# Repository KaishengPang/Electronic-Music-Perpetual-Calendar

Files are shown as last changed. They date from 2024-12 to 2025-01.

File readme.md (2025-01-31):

# Electronic Music Perpetual Calendar 🕰️📅
## 外观展示⏰

<div align=center>
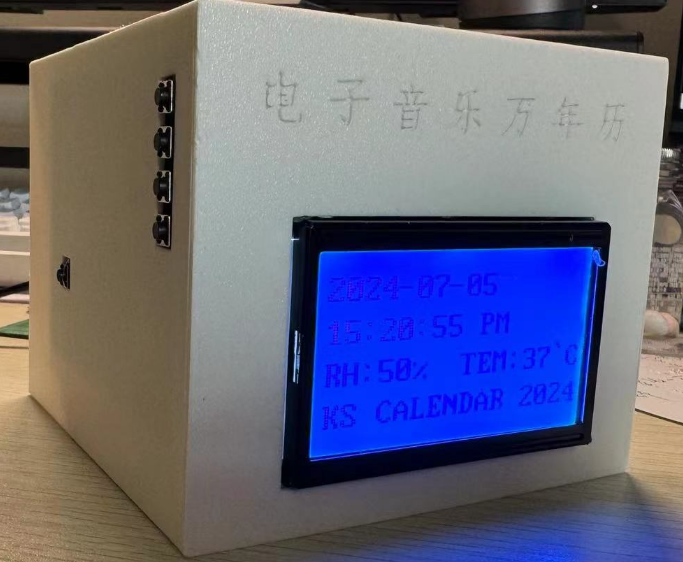
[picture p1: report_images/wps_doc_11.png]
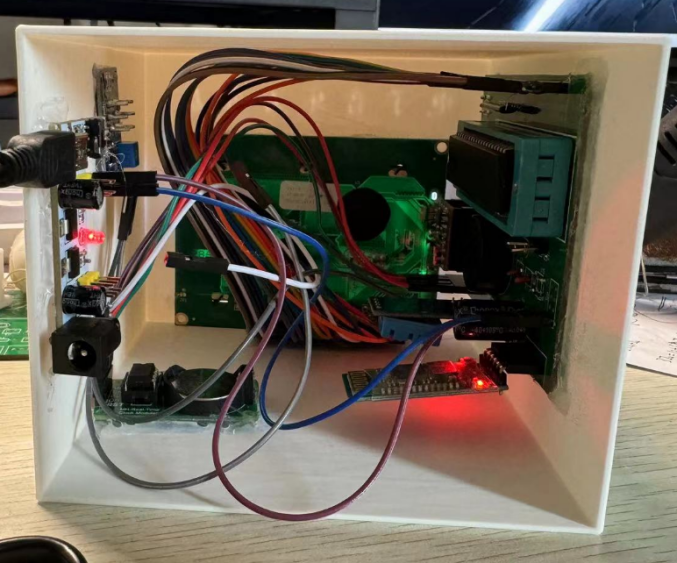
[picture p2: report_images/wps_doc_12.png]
 
</div>

欢迎来到 Electronic Music Perpetual Calendar 项目！本项目基于 [Smart-Calendar-Clock](https://github.com/genglinWang/Smart-Calendar-Clock) 进行了全面优化与功能扩展，打造了一款融合物联网与智能交互的创新硬件产品。

> 📜 本项目为山东大学信息学院《开放性创新实践Ⅰ—硬件》课程成果

## 项目亮点 ✨✨✨

### 全栈式开发闭环
🖨️ **3D打印一体化外壳** - SolidWorks建模实现物理按键与PCB板完美嵌合  
🔩 **双版本PCB迭代** - 从15x10cm优化至8.6x7.4cm，支持背焊式按键设计  
🔥 **火灾应急系统** - MQ-2烟雾传感器+短信报警双保险机制  

### 功能全景图
📅 **日历系统**  
- 公历/农历双模式 | 二十四节气 | 星期显示 
- 事件提醒（生日/会议/作业）⏰ 提前1天弹窗预警  
- 闹钟时间设置，闹钟时间到进行声光报警提示🚨

🌡️ **环境感知**  
- DHT11温湿度实时监测  
- 蓝牙天气同步（晴/雨/多云等8种状态）
- MQ-2烟雾传感器🔥+短信✉️报警双保险机制  

🎵 **智能交互**  
- 手机APP进行时间调整、事项提醒、天气更新
- JQ8900音乐芯片支持6首闹铃可选  
- MIT App Inventor开发跨平台控制APP  

<div align=center>
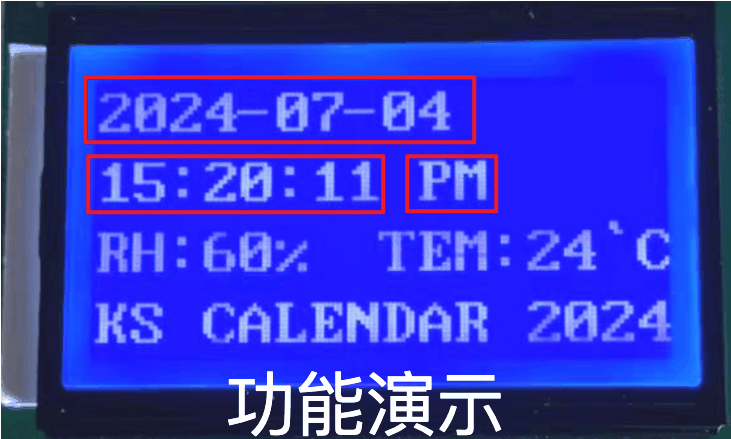
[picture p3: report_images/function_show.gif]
 
</div>

## 硬件架构 📐
### 原理图

<div align=center>
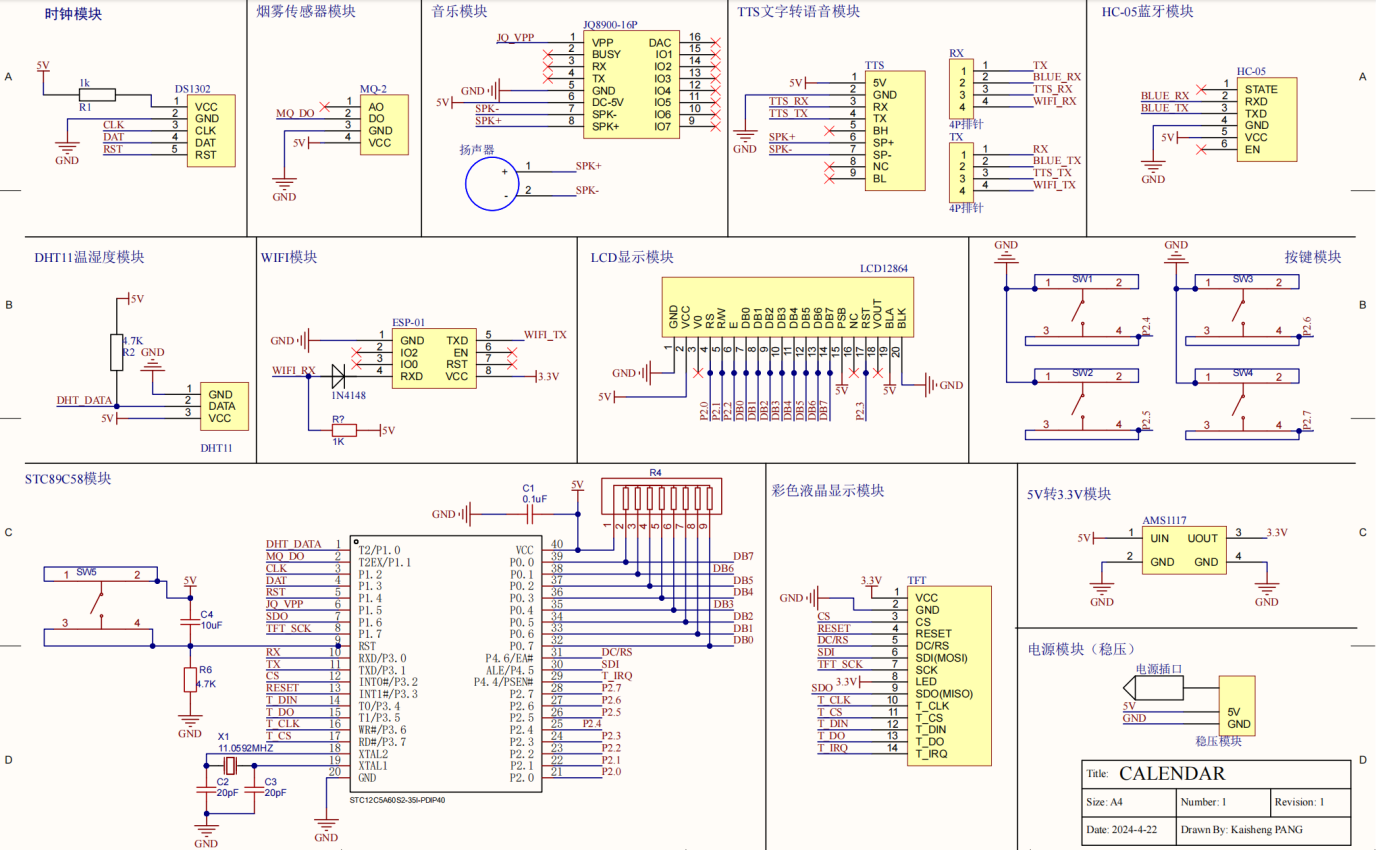
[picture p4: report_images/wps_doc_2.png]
 
</div>

### 3D打印效果图

<div align=center>
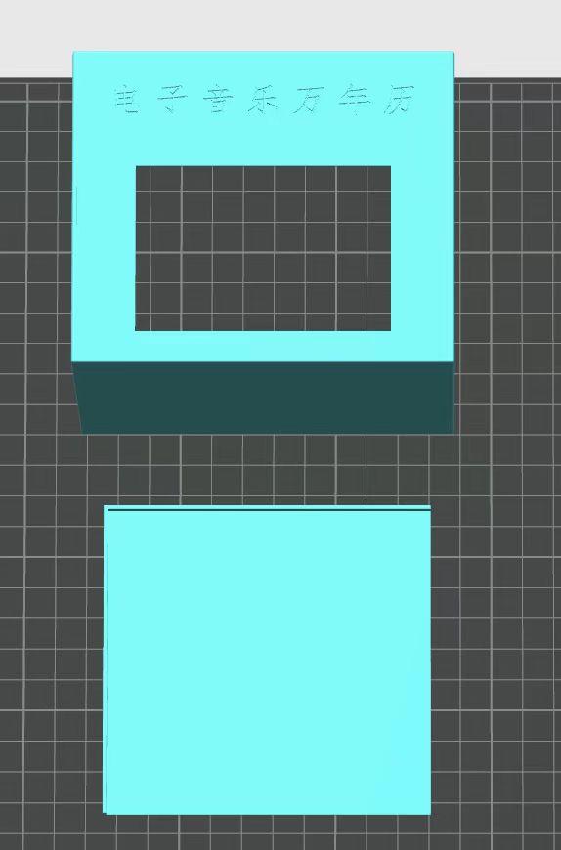
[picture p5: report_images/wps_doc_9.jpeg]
 
</div>

### PCB设计效果图

<div align=center>
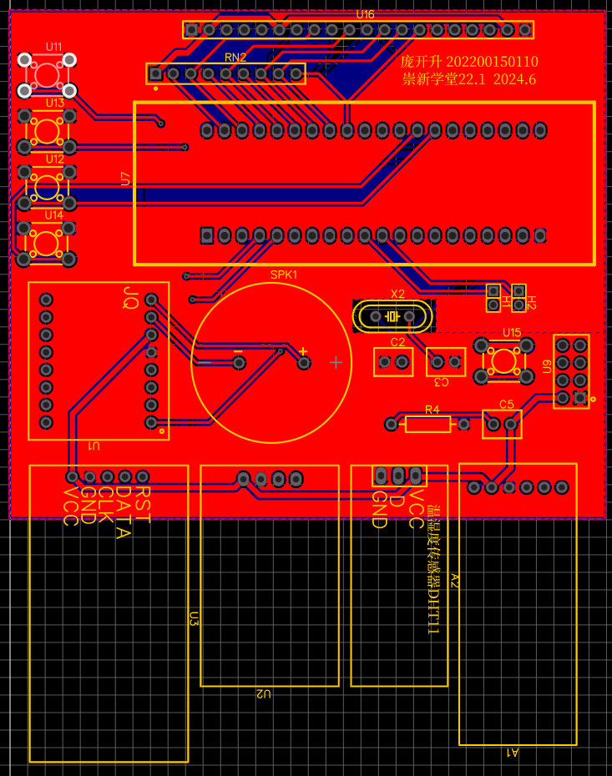
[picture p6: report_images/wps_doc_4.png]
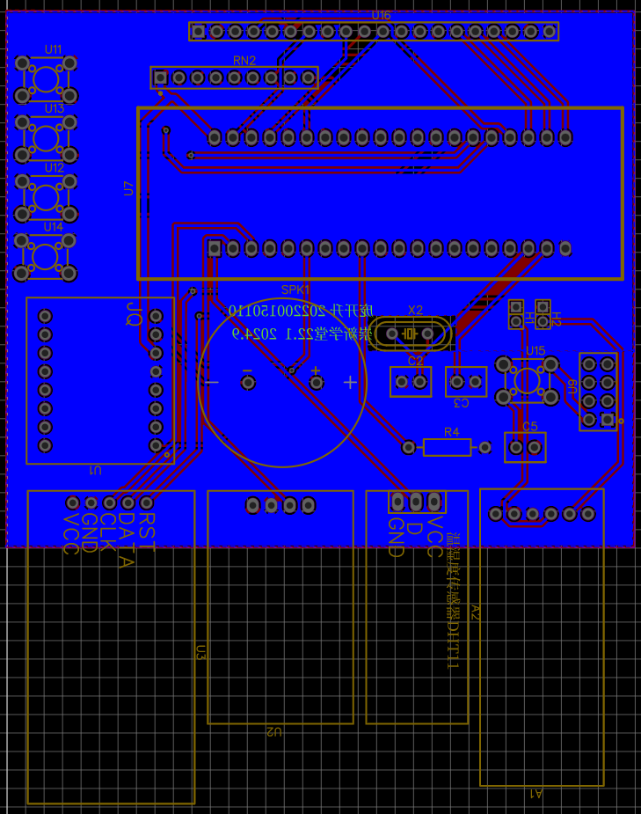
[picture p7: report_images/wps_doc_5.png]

</div>

### 核心模块清单
| 模块 | 型号 | 特性 |
|---|---|---|
| MCU | STC12C5A6052 | 低功耗高速8051内核 |
| 时钟 | DS1302 | 纽扣电池供电持续计时 |
| 显示 | LCD12864 | 自定义汉字库支持 |
| 音乐 | JQ8900-16P | 播放自定义铃声 |
| 通信 | HC-05蓝牙 | 安卓/iOS全平台兼容 |
| 传感器 | MQ-2+DHT11 | 火灾/温湿度双重监测 |

### PCB进化史
<div align=center>
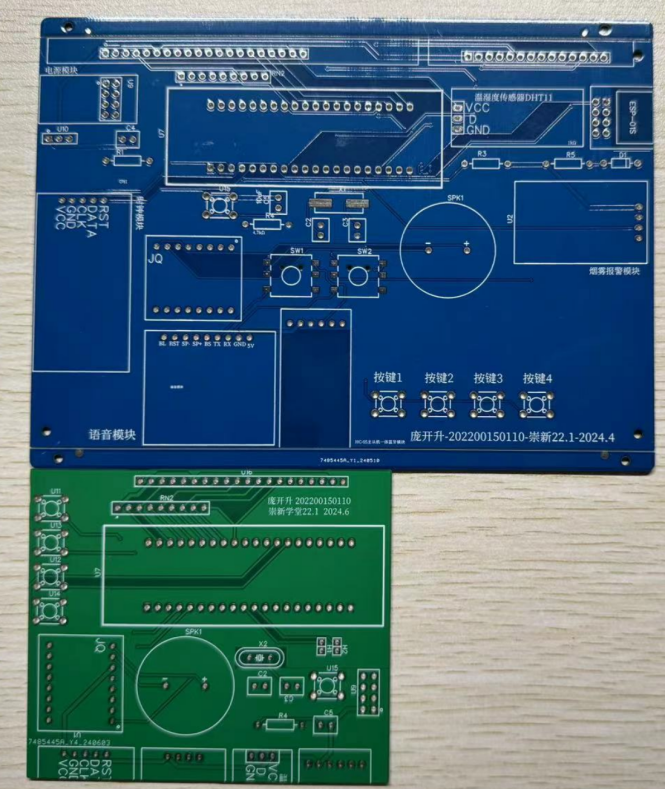
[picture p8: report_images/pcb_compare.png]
 
</div>

- **V1痛点**：WIFI/蓝牙冲突 | 布局冗余 | 供电不稳  
- **V2突破**：精简模块位置 | 背焊式按键设计 | 与3D打印结合

## 项目开发流程 🛠️

### 1. 原理图设计 📐
利用 **Altium Designer** 设计该系统的原理图：
- **模块化设计**：将系统分为MCU、时钟、传感器、显示、通信等模块。
- **电平转换**：在WIFI_RX处添加电平转换设计，确保信号稳定性。
- **模块选择**：
  - MCU：STC12C5A6052
  - 时钟：DS1302
  - 传感器：MQ-2（烟雾）、DHT11（温湿度）
  - 显示：LCD12864
  - 通信：HC-05（蓝牙）、ESP-01（WiFi）
  - 电源：AMS1117（5V转3.3V）

### 2. PCB设计 🖨️
利用 **Altium Designer** 设计PCB板图，并委托制板厂家加工：
- **PCB尺寸**：第一版为15x10cm，第二版优化为8.6x7.4cm。
- **线宽设置**：供电和接地线宽为30mil，其余线宽为10mil。
- **文字标识**：在PCB板上添加学号和姓名文字标识。
- **优化改进**：
  - 去掉ESP-01S WiFi模块，避免与蓝牙冲突。
  - 使用排针形式引出TX、RX，解决开关自动复位问题。
  - 加入稳压模块，解决DC供电电压偏差问题。

### 3. 焊接与调试 🔧
焊接元器件并进行实物调试：
- **第一版焊接**：LCD12864显示不稳定，PCB接触不良，通讯复杂。
- **第二版焊接**：焊接效果良好，蓝牙通讯恢复正常，空间利用率高。
- **调试重点**：
  - 确保LCD12864显示稳定。
  - 测试蓝牙、WiFi通信功能。
  - 验证温湿度传感器和烟雾传感器数据准确性。

### 4. 3D打印与外壳制作 🖌️
进行 **3D打印**，制作配套机壳：
- **设计工具**：使用 **SolidWorks** 进行建模。
- **外壳设计**：
  - 创建基本外壳，添加显示屏、按钮、烟雾传感器的开口。
  - 调整外壳厚度，添加圆角，增强美观性和结构强度。
- **按钮设计**：从背面焊接按钮，搭配3D打印外壳，实现原始触发且灵敏。
- **固定方式**：使用热熔胶固定内部元件，确保稳固性。

### 5. 设计报告编写 📄
编写设计报告，包含软硬件设计思路和效果展示：
- **硬件设计**：
  - 原理图设计思路。
  - PCB布局优化过程。
  - 焊接调试问题与解决方案。
- **软件设计**：
  - 蓝牙连接逻辑。
  - 时间、闹钟设置功能实现。
  - 事件提醒与天气显示逻辑。
- **效果展示**：
  - 3D外壳效果图。
  - 功能演示截图（时间显示、温湿度检测、闹钟设置等）。
  - 手机APP界面截图。

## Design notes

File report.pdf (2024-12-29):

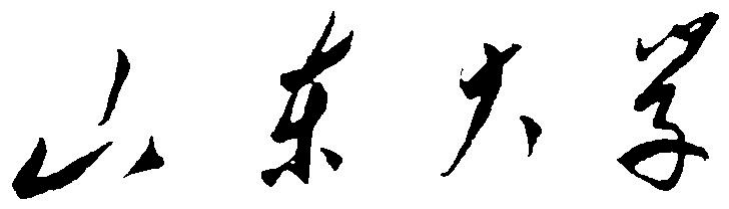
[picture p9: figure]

# 崇新学堂

### 2023－2024 学年第二学期

# 电子音乐万年历报告

课 | 程 | 名 | 称： 开放性创新实践Ⅰ—硬件
课 | 程 | 部 | 分： | 硬件报告
专 | 业 | 班 | 级： | 崇新 22.1
学 | 生 | 姓 | 名： | 庞开升
学 | 生 | 学 | 号：
报 | 告 | 时 | 间： | 2024.7.3

山东大学·崇新学堂·实验报告

目录

### 1 项目功能要求

### 1.1 基本功能

●年、月、日、时、分、秒、星期的显示与设置
●AM、PM 设置与显示
●农历年月日、二十四节气显示
●闹钟时间设置，闹钟时间到进行声光报警提示
●温湿度检测与显示

### 1.2 高级功能

●闹钟音乐选择（采用 TF 卡或录音芯片存储音乐数据）
●手机通过蓝牙或 WiFi 网络连接该万年历，通过手机 APP 可以完成基本功能中的所有 设置功能
●事件提示设置，可以通过手机或电脑将重要事件信息发送给系统，系统在事件发生前 一日通过字幕提醒（比如某某人的生日，某某会议等）
●通过编写 Android 手机程序或者将万年历连接到电脑上，获得网上天气预报数据，并 将该数据通过蓝牙或 WiFi 网络传递给音乐万年历，万年历可以完成天气信息显示 ●火灾检测与声光报警，报警形势可以是短信。

### 2 实现步骤

●利用 Altium Designer 设计该系统的原理图
●利用 Altium Designer 设计该系统的 PCB 板图，并委托制板厂家加工，板上要有学号 姓名文字标识
●焊接元器件进行实物调试
●进行 3D 打印，配套机壳，做成能实用的万年历！
●编写设计报告，包含相应的软硬件设计思路描述，设计效果展示

### 3 原理图绘制

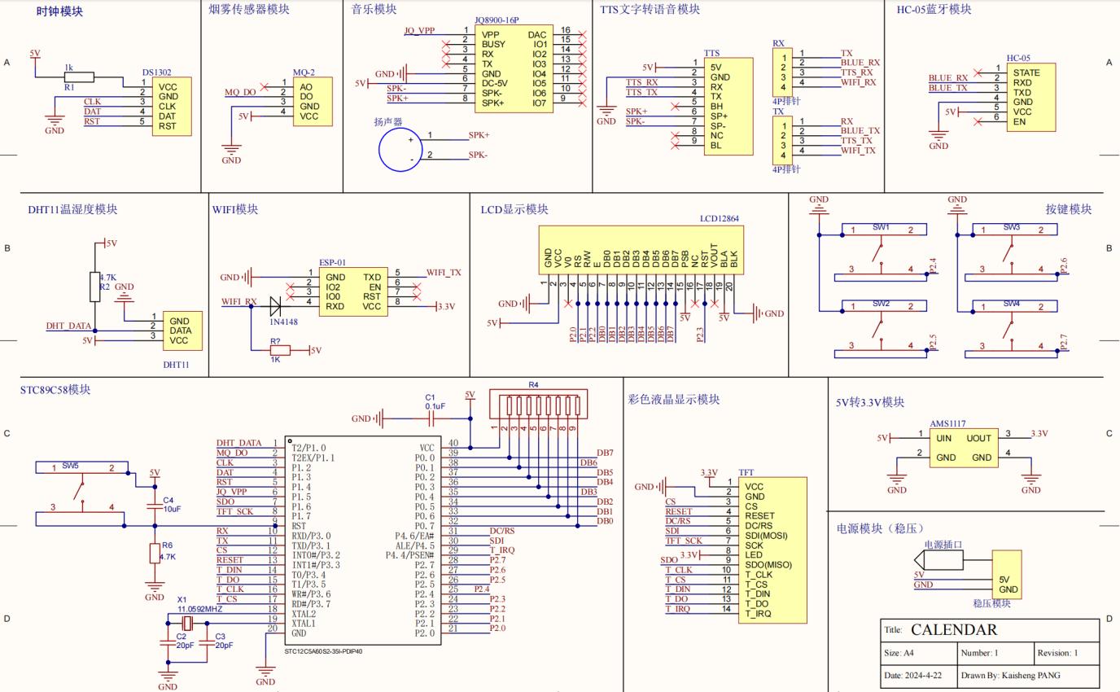
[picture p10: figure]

根据设计要求，设计了第一版原理图，根据老师提示，在 WIFI_RX 处添加电平转 换设计。

### 3.1 设计 PCB 板

### 3.1.1 第一版 PCB

根据原理图设计 PCB，因为显示屏占据空间较大，选用 15*10 尺寸的 PCB 板，供 电和接地线宽为 30mil，其余线宽为 10mil。这是第一版的 PCB，但经过测试，发现存 在很多问题。

模块名称 | 具体选择
MCU | STC12C5A60S2
时钟 | DS1302
烟雾传感 | MQ-2
音乐 | JQ8900-16P
文字转语音 | TTS
蓝牙 | HC-05
温湿度传感 | DHT11
WIFI | ESP-01
LCD 显示 | LCD12864
彩色液晶显示 | TFT
5V 转 3.3V | AMS1117

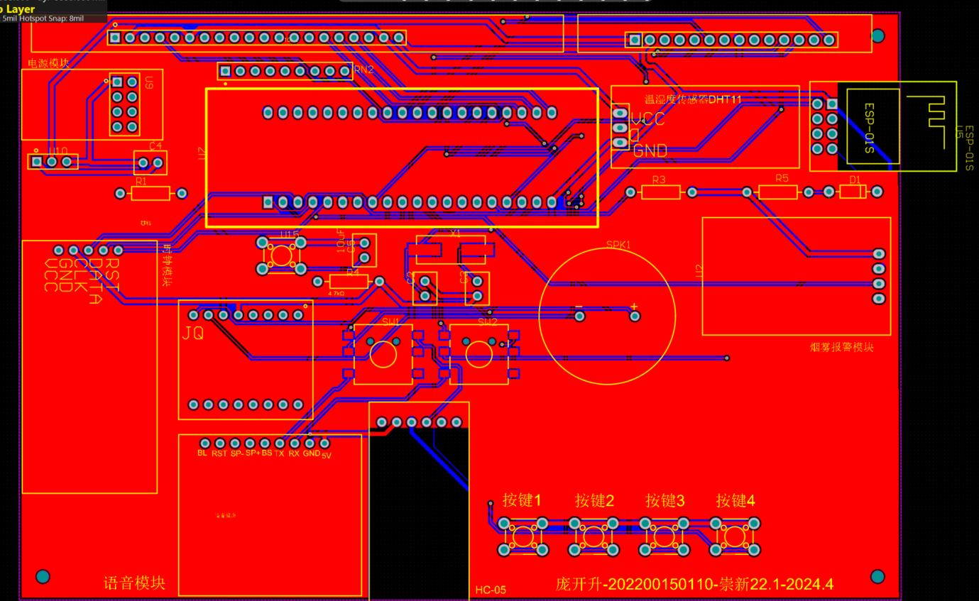
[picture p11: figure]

问题汇总及修正解决：

序号 | 问题描述 | 解决方案
1 | PCB 设计的模块方向和大小造成空间浪费 | 改进 PCB 布局与设计
2 | 同时使用ESP-01S WIFI和HC-05冲突且意义不大 去掉 ESP-01S
3 | TX、RX 分别要连接三个模块，所以使用了一款
| 五个方向的开关，可是这款开关会自动复位！ | 换成排针形式，将 TX、RX
| | 各自引出
4 | TFT 显示内容太占据内存，C58 不能胜任 | 去掉 TFT 显示屏
5 | DC 供电电压偏差太大 | 加入稳压模块

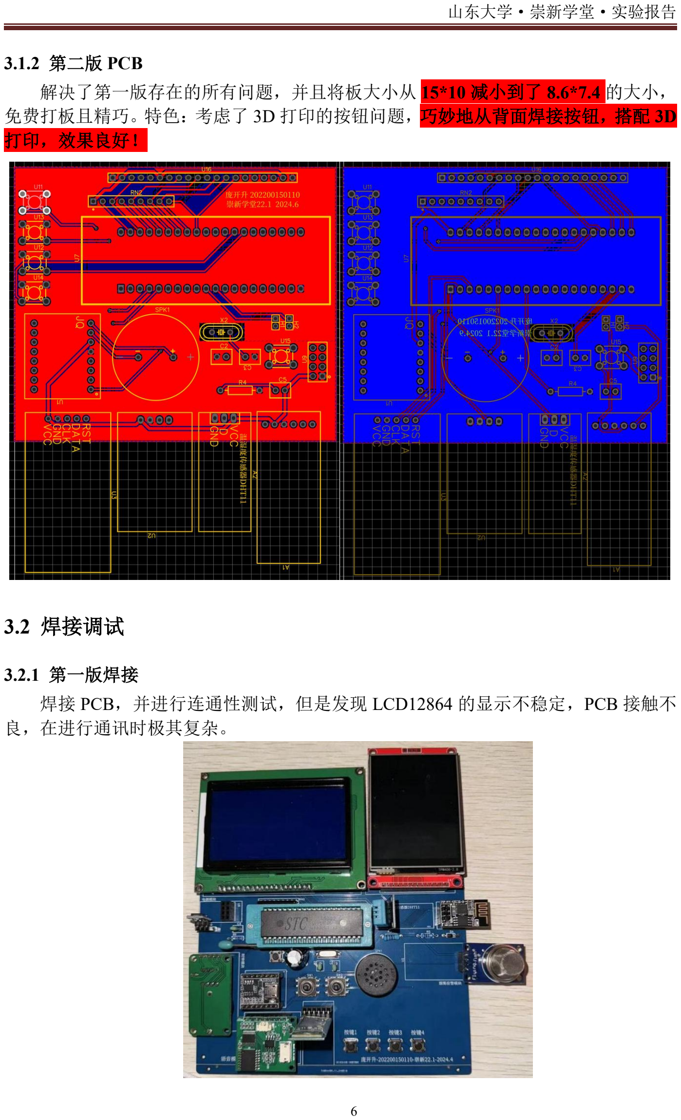
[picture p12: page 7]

### 3.1.2 第二版 PCB

解决了第一版存在的所有问题，并且将板大小从 15*10 减小到了 8.6*7.4 的大小， 免费打板且精巧。特色：考虑了 3D 打印的按钮问题，巧妙地从背面焊接按钮，搭配 3D 打印，效果良好！

### 3.2 焊接调试

### 3.2.1 第一版焊接

焊接 PCB，并进行连通性测试，但是发现 LCD12864 的显示不稳定，PCB 接触不 良，在进行通讯时极其复杂。

### 3.2.2 第二版焊接

这次焊接效果良好，大大节约了空间，充分利用板外空间，蓝牙通讯也恢复正常。

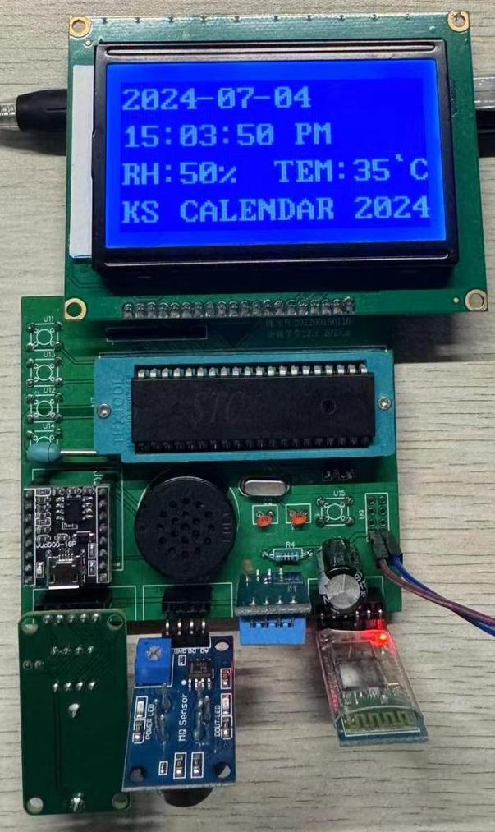
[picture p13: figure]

### 3.2.3 第一、二次 PCB 比较

很直观地看到了 PCB 制版的差别，提升显著。

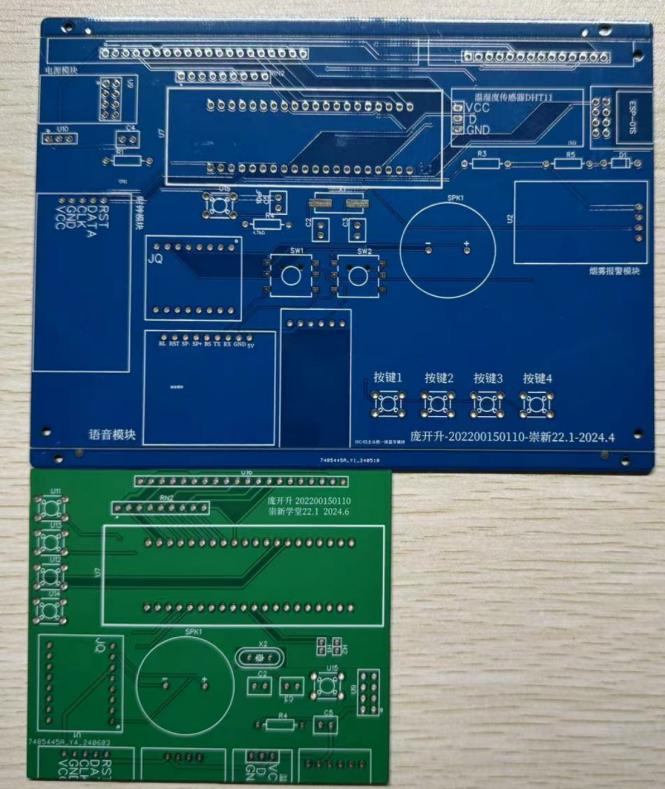
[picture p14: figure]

4 3D 外壳制作

使用 SolidWorks 建模，制作了一个外壳以及一个后盖，将显示屏、按钮、烟雾传 感器进行挖孔，将器件从里面穿出，便于显示、操控与检测。
步骤如下：
1.创建基本外壳
●在前视平面上绘制一个矩形。
●使用拉伸凸台/基体功能将矩形拉伸成一个长方体，这将成为外壳的基本形状。
2. 添加开口和孔
●在合适的平面上绘制所需的开口和孔的轮廓。
●使用切除拉伸功能来切除这些开口和孔。可以根据实际需要调整开口和孔的位置和大 小。在前视平面上绘制一个矩形，用于显示屏开口，然后使用切除功能切出这个开口。 ●在侧视平面上绘制两个小矩形，用于按键开口，然后使用切除功能切出这些开口。
3. 添加文字
●在前视平面上使用文本工具添加所需的文字。
●调整文字的位置和大小，然后使用切除拉伸功能将文字凹陷进去。
4. 调整厚度
●使用壳工具将外壳的壁厚调整为所需的厚度。选择壳工具，然后选择要保持厚度的面， 输入所需的厚度值。
5. 添加圆角
●使用圆角工具在外壳的边缘添加圆角，增加外壳的美观性和结构强度。
6. 检查和调整
●旋转和查看 3D 模型，确保所有开口、孔和文字都在正确的位置。 ●根据需要进行调整，以确保外壳符合设计要求。
7. 保存文件
●完成设计后，保存 SolidWorks 文件（.sldprt），并根据需要导出为 STL 用于 3D 打印 或其他制造工艺。
建模图：

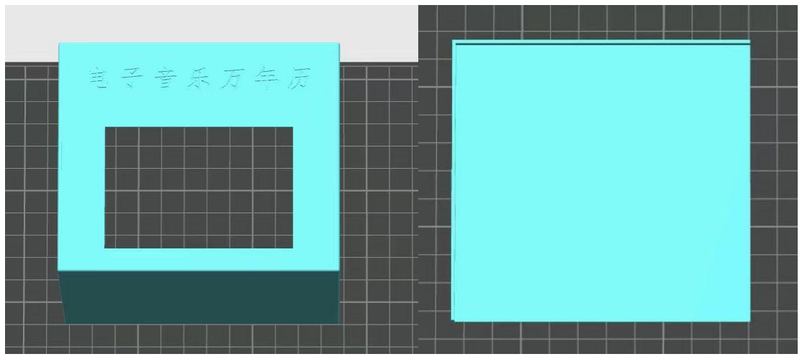
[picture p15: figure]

效果图：

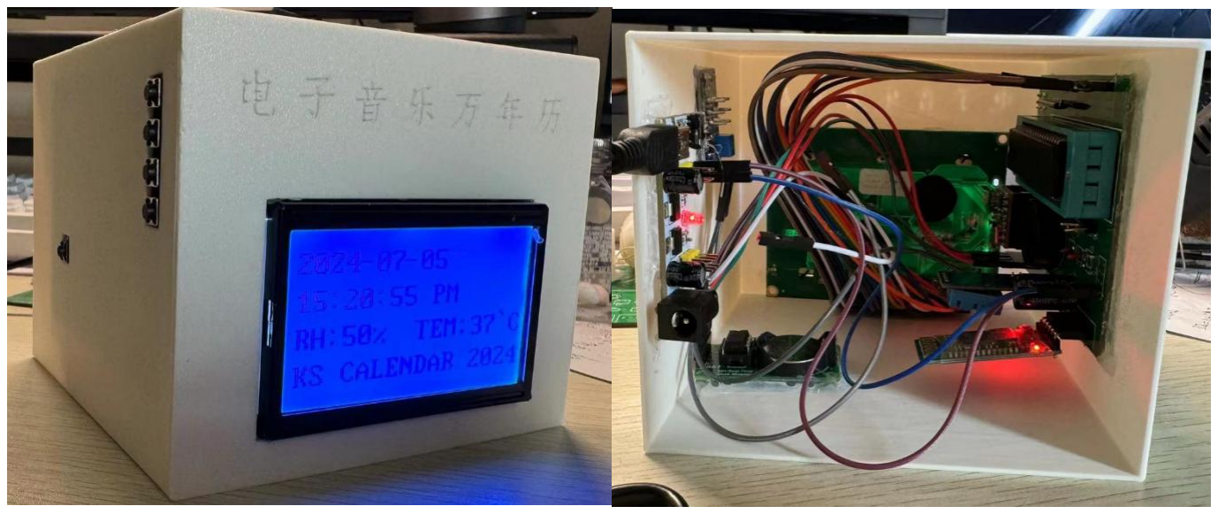
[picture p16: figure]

### 5 功能完成情况

所有功能全部完成，共十项，基本功能高级功能各五项。

### 5.1 年、月、日、时、分、秒的显示与设置（基本功能 1）

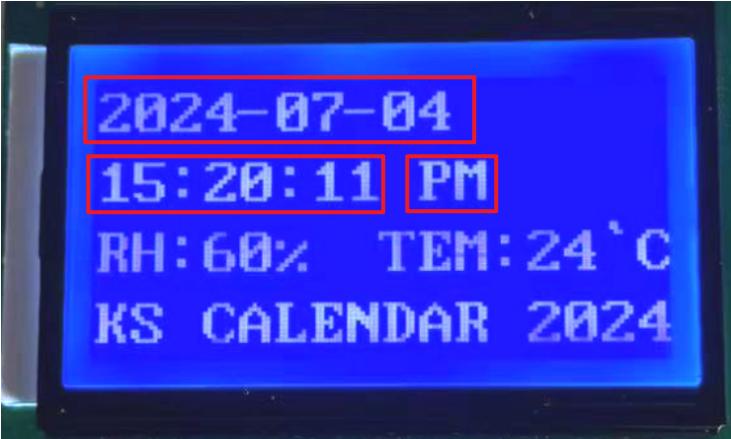
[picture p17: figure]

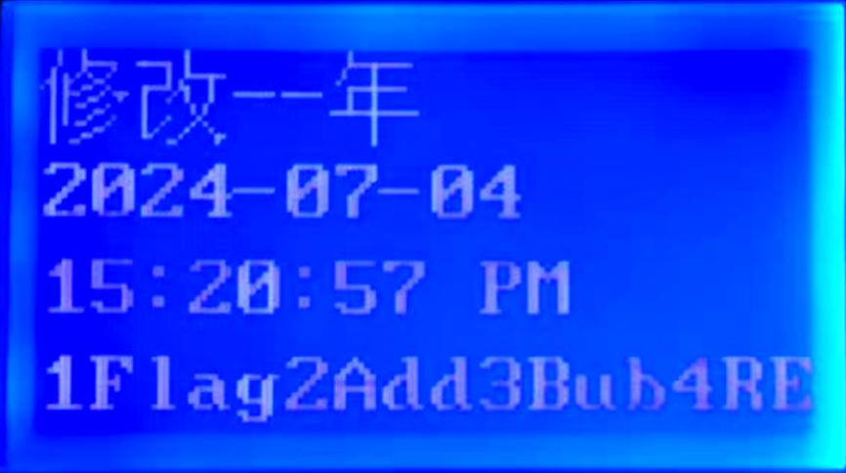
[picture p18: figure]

### 5.2 年、月、日、时、分、秒的显示与设置（基本功能 2）

### 5.3 农历年月日、二十四节气、星期显示（基本功能 1、3）

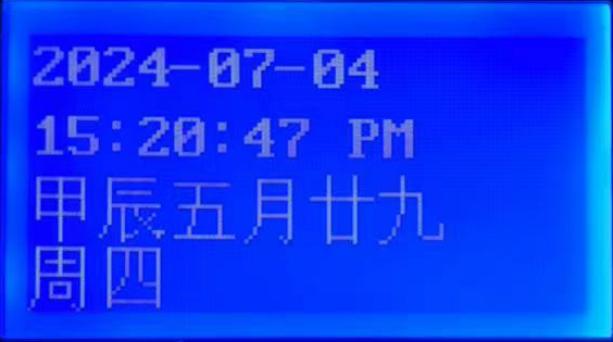
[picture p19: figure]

### 5.4 闹钟时间设置，闹钟时间到进行声光报警提示（基本功能 4）

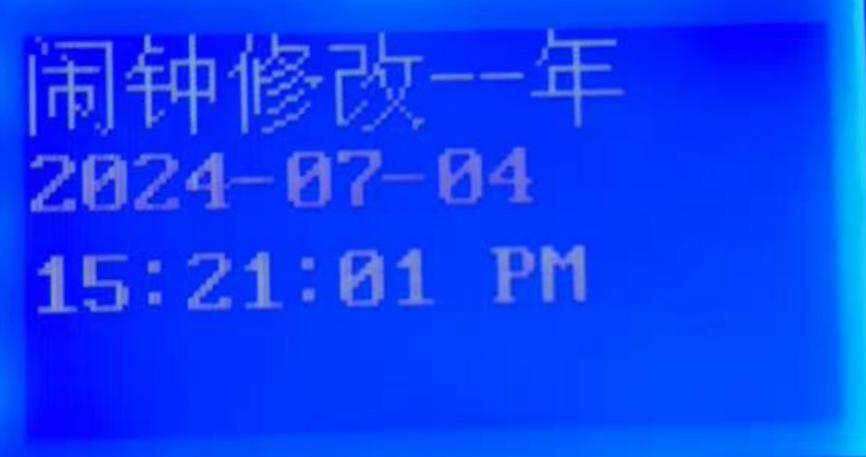
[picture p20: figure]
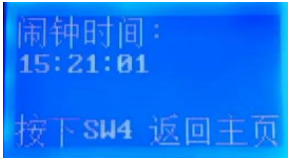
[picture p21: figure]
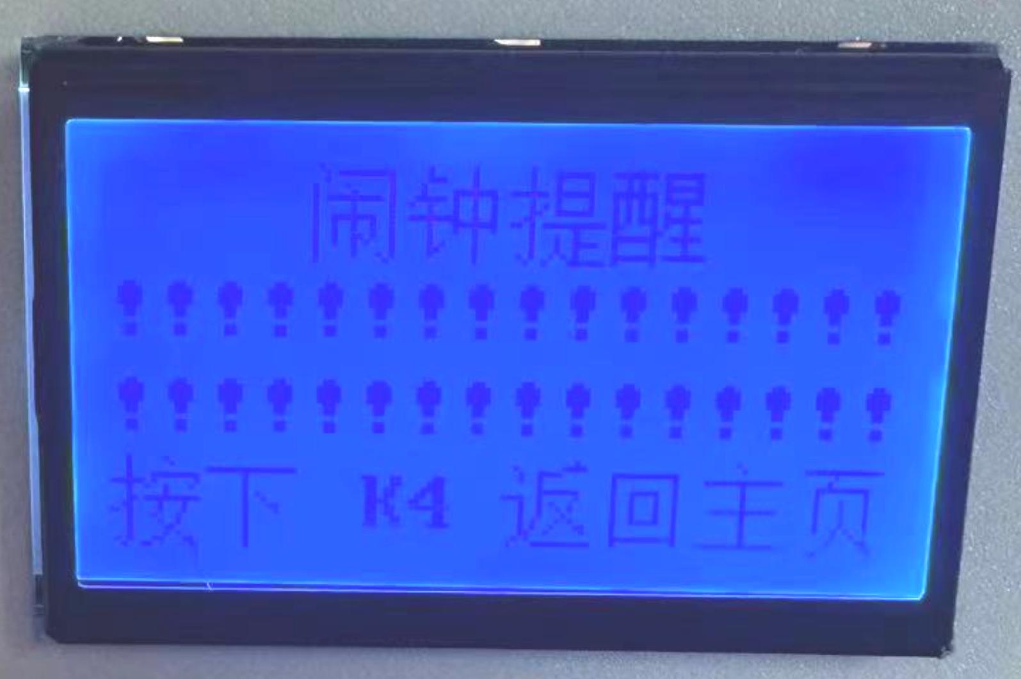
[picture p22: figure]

### 5.5 温湿度检测与显示（基本功能 5）

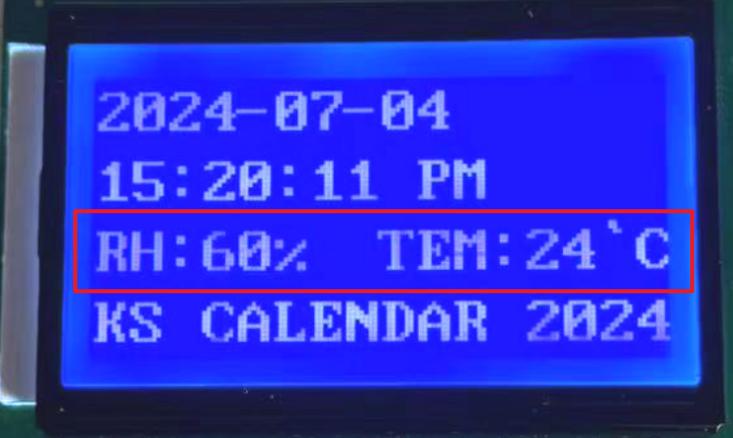
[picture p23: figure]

### 5.6 闹钟音乐选择（高级功能 1）

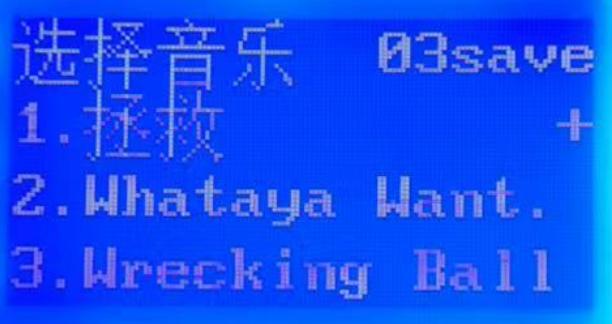
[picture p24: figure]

### 5.7 手机 APP 可以完成基本功能中的所有设置功能

### 5.8 事件提示

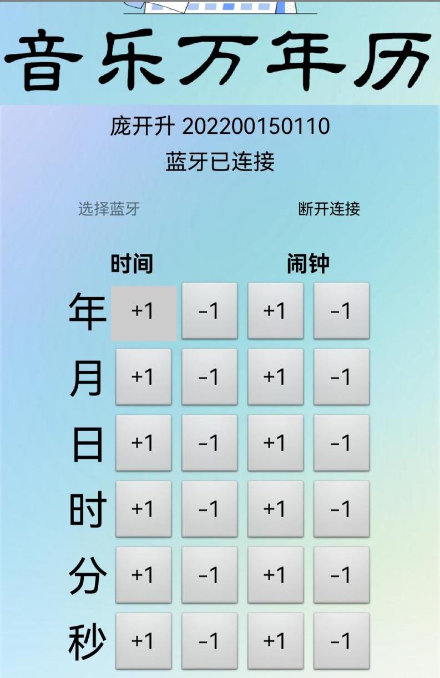
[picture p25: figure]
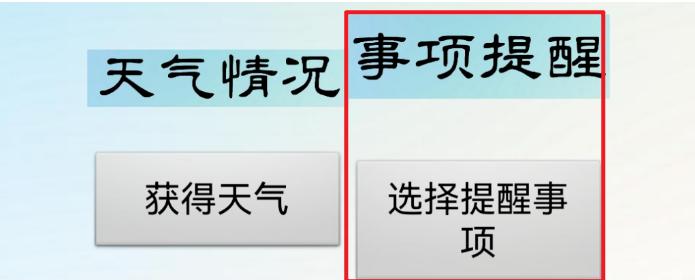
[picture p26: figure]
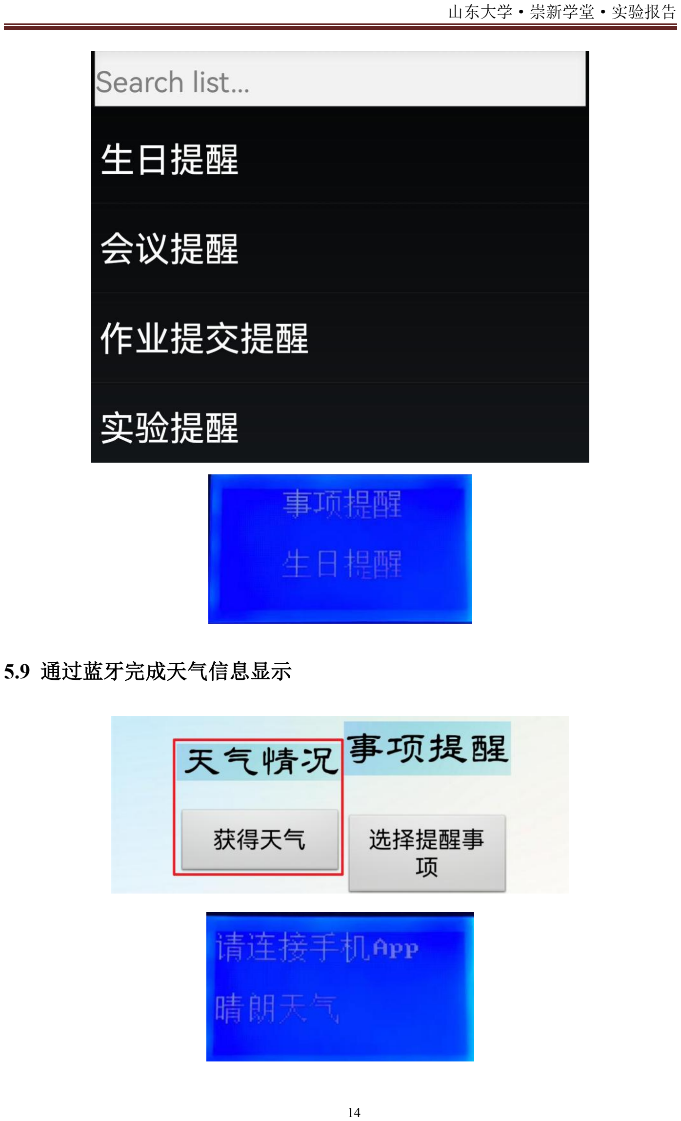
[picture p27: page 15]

### 5.9 通过蓝牙完成天气信息显示

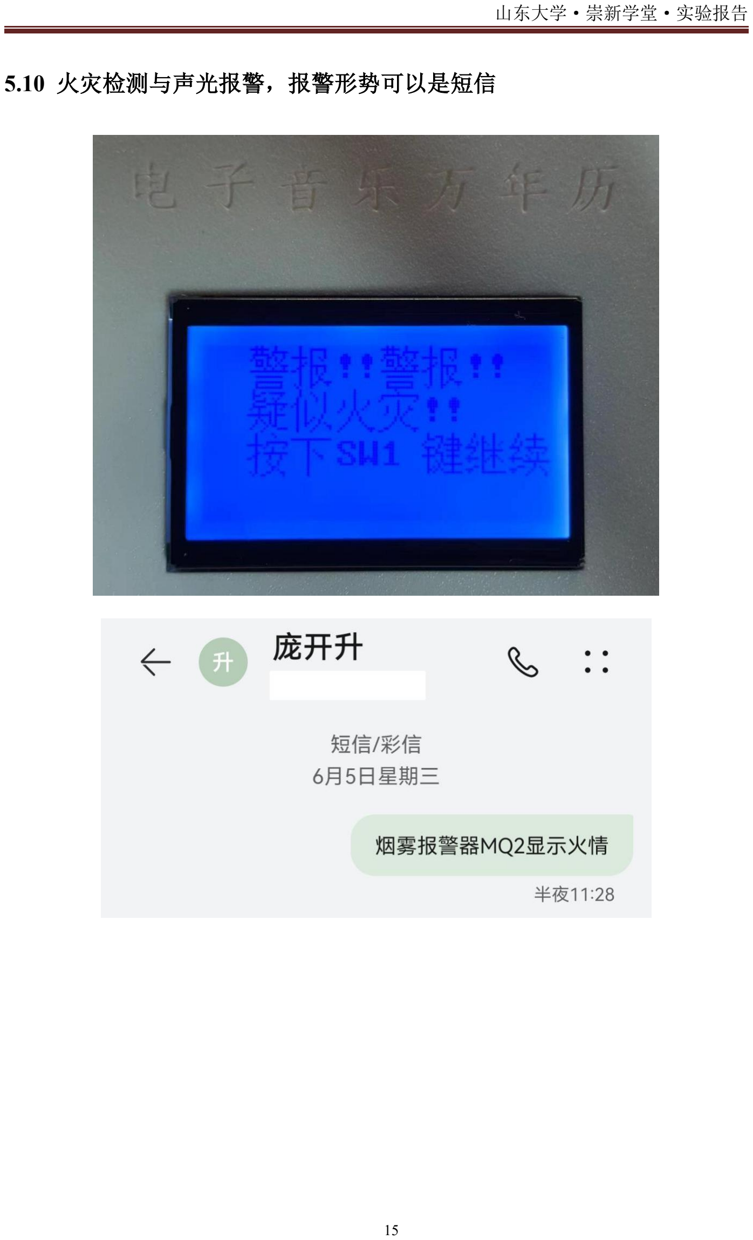
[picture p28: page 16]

### 5.10 火灾检测与声光报警，报警形势可以是短信

### 6 代码

### 6.1 Main.c

函数名 | 功能介绍
main | 初始化蓝牙、屏幕和时钟；进入一个无限循环，显示时间、DHT11
| 传感器数据、以及按键检测和处理；处理闹钟提醒和火灾警报检测
Basic | 显示基本的日期和农历信息；通过按键返回主菜单
calculateWeekDay 计算给定日期的星期几
callMenu | 显示并处理主菜单，用户可以选择进入不同的功能模块
getweather | 获取并显示天气信息
control | 显示提醒事项，如生日、会议等
6.2 12864.c
函数名 | 功能介绍
Switch_bit(uchar InChar) | 将输入的字符 InChar 进行位反转，具体是将字符的各个位交换顺
| 序
Display_String(uchar line, uchar *string) | 在指定的行 line 显示一个 16 位的字符串 string
Wr_Data(uchar wrdata) | 向 LCD 写入数据，使用 Switch_bit 函数进行数据位转换，然后
| 将数据发送到 LCD
Wr_Command(uchar wrcommand, busyc) | 向 LCD 发送命令，如果 busyc 为真，则在发送命令前进行忙等
| 待
RDbf(void) | 忙等待函数，检查 LCD 是否忙碌，如果忙则等待
Lcm_Init(void) | 初始化 LCD，包括复位和发送初始命令
Delay5Ms() | 延时 5 毫秒，用于 LCD 初始化和其他需要延时的地方

### 6.3 Ds1302.c

函数名 | 功能介绍
Ds1302Write(uchar addr, uchar dat) | 向 DS1302 写入命令（地址和数据），通过串行通信将数据发送
| 到指定的地址
Ds1302Read(uchar addr) | 从 DS1302 读取指定地址的数据，通过串行通信接收数据
Ds1302Init() | 初始化 DS1302 时钟芯片，禁用写保护，设置初始时间，然后重
| 新启用写保护。
Ds1302ReadTime() | 读取 DS1302 的当前时间信息（秒、分、时、日、月、年），并
| 存储在 TIME 数组中。
dataProcess() | 将 DS1302 读取的时间数据转化为可显示在 12864 LCD 上的字
| 符串格式
dataProcess_new() | 类似于 dataProcess()，但使用 buffer 数组处理时间数据

dataChange() | 修改 DS1302 中的时间，通过用户输入调整年、月、日、时、分、
| 秒，然后将修改后的时间写回 DS1302
setClock() | 设置闹钟时间，通过用户输入调整年、月、日、时、分、秒，更新
| clocktime 数组。
alarmDetect() | 检测当前时间是否与设定的闹钟时间一致，如果一致则返回 1，否
| 则返回 0。
blue2time(uchar flag, uchar pos) | 通过蓝牙修改 DS1302 的时间，根据 flag 和 pos 调整相应位置
| 的时间值。
blue2clocktime(ucha r flag, uchar pos) | 通过蓝牙修改闹钟时间，根据 flag 和 pos 调整 clocktime 数组中
| 的时间值。

### 6.4 Dht11.c

函数名 | 功能介绍
DHT11_delay_us(uchar n) 微秒级延时函数，延时 n 微秒。
DHT11_delay_ms(uint z) | 毫秒级延时函数，延时 z 毫秒。
Delay30us() | 延时 30 微秒的函数，使用 11.0592MHz 的时钟频率。
DHT11_start() | 初始化 DHT11 传感器，发送启动信号以开始温湿度数据的传输。
DHT11_rec_byte() | 接收 DHT11 传感器发送的一个字节数据，通过轮询数据线的电平
| 变化来读取每一位。
DHT11_receive() | 接收 DHT11 传感器的数据，并将其格式化为可显示在 LCD12864
| 上的 16 位字符串格式。读取湿度和温度数据，并检查数据校验和
| 是否正确。格式化湿度和温度数据为字符串，"RH % TEM `C"。

### 6.5 jq8900.c

函数名 | 功能介绍
Delay1500us() Delay500us()
Delay2ms() Delay4ms() | 这些是延时子函数，用于产生不同的延时，用于控制通信时序
SendData(uint addr) | 向 JQ8900 模块发送指令，通过一线通信协议发送数据；常见指令
| 包括重复播放（0x11）、结束播放（0x13）、清除数字（0x0a）和
| 选曲确认（0x0b）。
Musicselect() | 音乐选择子函数，用户可以通过按键选择不同的歌曲；共有六首歌
| 曲存储在 JQ8900 的 SD 卡中，通过全局变量 song 存储选择的
| 歌曲序号，并通过 SendData(song) 进行播放

### 6.6 keyscan.c

函数名 | 功能介绍
key_scan() | 按键检测函数，仅支持单点检测，不支持连点和多点检测。返回键
| 值 1-4。检测 P2 端口的 4 个引脚状态，确定哪个按键被按下。
| 如果有按键按下，进行去抖动处理，并返回对应的键值。

### 6.7 Lunar.c

函数名 | 功能介绍
LunarCalendar(int year, int month, int day)

计算阳历日期对应的农历日期；根据给定的阳历年份、月份和日期， 计 算 出 农 历 的 年 份 、 月 份 和 日 期 ， 并 将 结 果 存 储 在
LunarCalendarDay 中。
lunar_calendar(int *solar, uchar *lunar)

接 受 阳 历 日 期 数 组 solar 和 农 历 结 果 数 组 lunar ； 调 用 LunarCalendar 函数，转换阳历日期为农历日期，并将结果存储在
lunar 中。
turn_lunar_calendar(uint
year, uchar month, uchar day, uchar *lunar)

转换阳历日期为农历日期；接受阳历年份、月份和日期，并将结果 存储在 lunar 数组中。

judgeSolar(uint year, uchar month, uchar day)

判断给定日期是否为节气日；根据节气表 jieqi 和输入的阳历日 期，返回对应的节气编号。

### 6.8 Bluetooth.c

函数名 | 功能介绍
Uart_Isr() | 串口中断服务程序，通过中断接收数据并进行处理；根据接收到的
数据调用 blue2time() 和 blue2clocktime() 函数来调整时间和闹钟
时间；如果接收到的值大于等于 25，则更新天气信息。
Uart_Init_blue() | 串口初始化函数，设置串口通信的参数，如工作模式、波特率等；
启动定时器 T1 用于生成波特率；使能全局中断和串口中断。
PostChar(uchar character) 通过串口发送一个字符，用于报警时发送短消息。

### 7 软件设计

使用 MIT Appinventor 进行开发，UI 界面如下，通过上方进行蓝牙连接或者断开， 左侧进行日期的控制，右侧进行闹钟的控制，最下面进行天气获取以及事项提醒，点击 即可将信息传入单片机中。

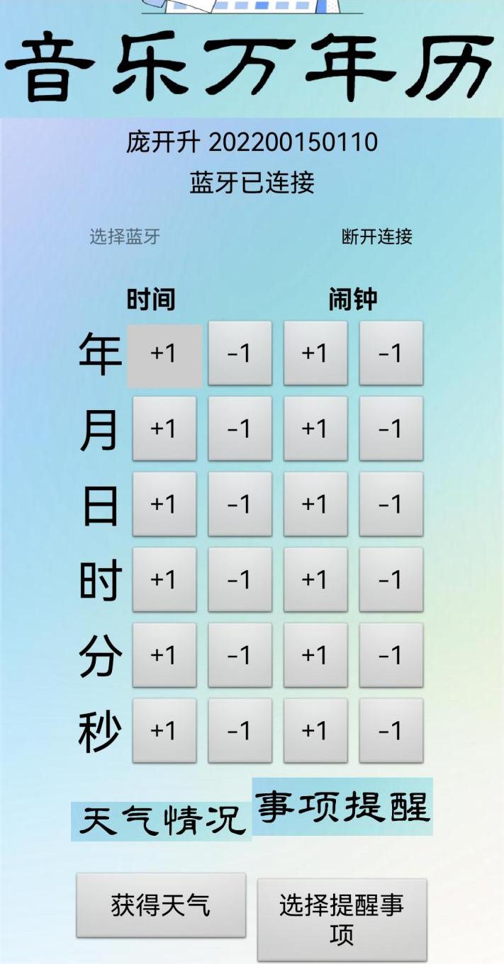
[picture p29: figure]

### 7.1 蓝牙连接程序逻辑

### 7.1.1 Screen1 初始化

●调用 蓝牙客户端 1 . 断开连接：在应用启动时，确保任何可能的蓝牙连接都被断开。 ●设置 列表选择框：选择蓝牙 . 启用 为 真：启用蓝牙选择框。
●设置 标签连接情况 . 文本 为 蓝牙未连接，单击蓝牙连接选择：更新界面标签，提 示用户蓝牙未连接，需要选择连接。

### 7.1.2 列表选择框：选择蓝牙准备选择

●调用 蓝牙客户端 1 . 获得设备 . 设备及名称：获取可用的蓝牙设备和名称。 ●设置 列表选择框：选择蓝牙 . 元素 为 蓝牙客户端 1 . 设备及名称：将获取的蓝牙 设备列表显示在选择框中。
●设置 标签连接情况 . 文本 为 准备连接：更新标签提示用户准备连接。

### 7.1.3 列表选择框：选择蓝牙选择完成

●调用 蓝牙客户端 1 . 连接 地址 为 列表选择框：选择蓝牙 . 选中项：尝试连接用户 选择的蓝牙设备。
●如果 蓝牙客户端 1 . 连接状态：
●否则：如果连接失败，更新标签提示蓝牙未连接。
●如果 蓝牙客户端 1 . 连接状态：再次检查连接状态，如果成功：
●设置 标签连接情况 . 文本 为 蓝牙已连接：更新标签提示蓝牙已连接。 ●设置 定时器 1 . 已启用 为 真：启用定时器，用于周期性检查状态。
●设置 标签 MQ2 . 文本 为 烟雾报警器 MQ2 显示火情：更新标签显示 MQ2 传 感器的火情状态。

### 7.1.4 按钮：断开连接被点击

●调用 蓝牙客户端 1 . 断开连接：在用户点击断开连接按钮时，断开蓝牙连接。 ●设置 列表选择框：选择蓝牙 . 启用 为 真：重新启用蓝牙选择框。
●设置 标签连接情况 . 文本 为 蓝牙未连接，单击蓝牙连接选择：更新标签提示蓝牙 未连接，用户需要重新选择连接。

### 7.2 时间、闹钟设置蓝牙发送阵列

通过对按钮点击设置蓝牙发送单字节数字，到单片机中解码，对应每一个按钮对应 的操作即可

### 7.3 事项提醒逻辑

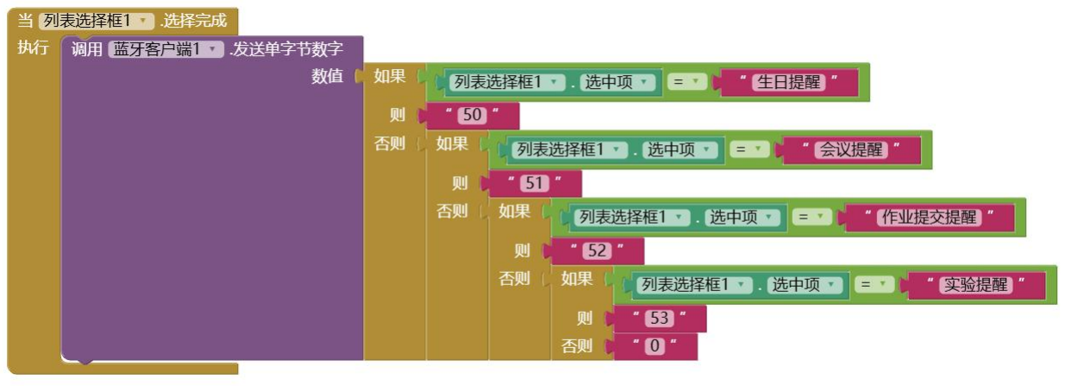
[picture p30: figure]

列表选择框 1：选择完成
调用 蓝牙客户端 1 . 发送单字节数字：发送一个单字节数字给蓝牙客户端。 数值：
如果 列表选择框 1 . 选中项 = "生日提醒" 发送数值 50

否则如果 列表选择框 1 . 选中项 = "会议提醒" 发送数值 51

否则如果 列表选择框 1 . 选中项 = "作业提交提醒" 发送数值 52

否则如果 列表选择框 1 . 选中项 = "实验提醒" 发送数值 53

否则
发送数值 0

### 7.4 天气逻辑

### 7.4.1 初始化变量

●初始化全局变量 (Json) 为 "0" ●初始化全局变量 weather 为 "0" 7.4.2 按钮：获取天气 -> 被点击

●调用 Web 客户端 1 . 执行 GET 请求
URL 设置为天气查询接口：
https://devapi.qweather.com/v7/weather/now?location=101120204&key=3130034d65904340 8fed902ab067ca2a

### 7.4.3 Web 客户端 1 -> 获取文本

●设置全局 Json 为：
在键 "now" 中查找关键字，如果未找到则返回 "not found" 在键 "text" 中查找关键字，如果未找到则返回 "not found" ●设置 global weather 为 全局 Json

通过解析 JSON 文本，获取当前的天气信息。

### 7.4.4 调用 蓝牙客户端 1 . 发送单字节数字

●根据 global weather 的值，发送相应的数值 如果 global weather 等于 "晴" 发送 25
如果 global weather 等于 "多云" 发送 26 如果 global weather 等于 "少云" 发送 27 如果 global weather 等于 "晴间多云" 发送 28 如果 global weather 等于 "阴" 发送 29
如果 global weather 等于 "阵雨" 发送 30 如果 global weather 等于 "强阵雨" 发送 31

如果 global weather 等于 "雷阵雨" 发送 32
其他的天气情况可按照相似逻辑处理

### 8 总结与心得

起初：从四月底就开始进行原理图和 PCB 的设计，第一版在五一之前就完成了，

当时也是有点急于求成，很多东西考虑的都不周全，但是在没有拿到具体实物之前就能

完美的制作确实需要更多的经验。

中程：从五月开始，发现了第一次制板的所有问题，逐一解决，用了两个小时就重

新设计了新的原理图和 PCB 板，并且这时候就有了想要制作 3D 外壳的想法，我就在想

到底怎么设计才能让外壳上的按钮触发 PCB 上的按键，想了很久，突然想到在 pcb 背

面焊接按钮，然后 3D 打印留出孔即可，果然效果很好，原始触发且灵敏，最后用热熔

胶固定住以后也比较牢靠。之后就在面包板上进行全面的调试，写完了所有代码，再焊

接了第二板 PCB，一通电就正常工作了，那一瞬间还是很开心的。

收尾：设计了手机 APP，调整了 UI 界面，使界面看起来更好看，然后学习设计了

逻辑，多次调试，最后打包成了 apk 软件！之后设计将所有零件合理的摆放在盒子内，

固定好，内部走线，做成了可实用的物品，效果良好！

过程中经历了很多问题，DEBUG 过程虽然已经很熟悉了，一层一层检查，但是还

总是会被一些硬件问题搞得摸不着头脑。这个过程积累了经验，从无到有，把一个项目

亲手做出来，以产品的角度考虑问题，颇有收获！

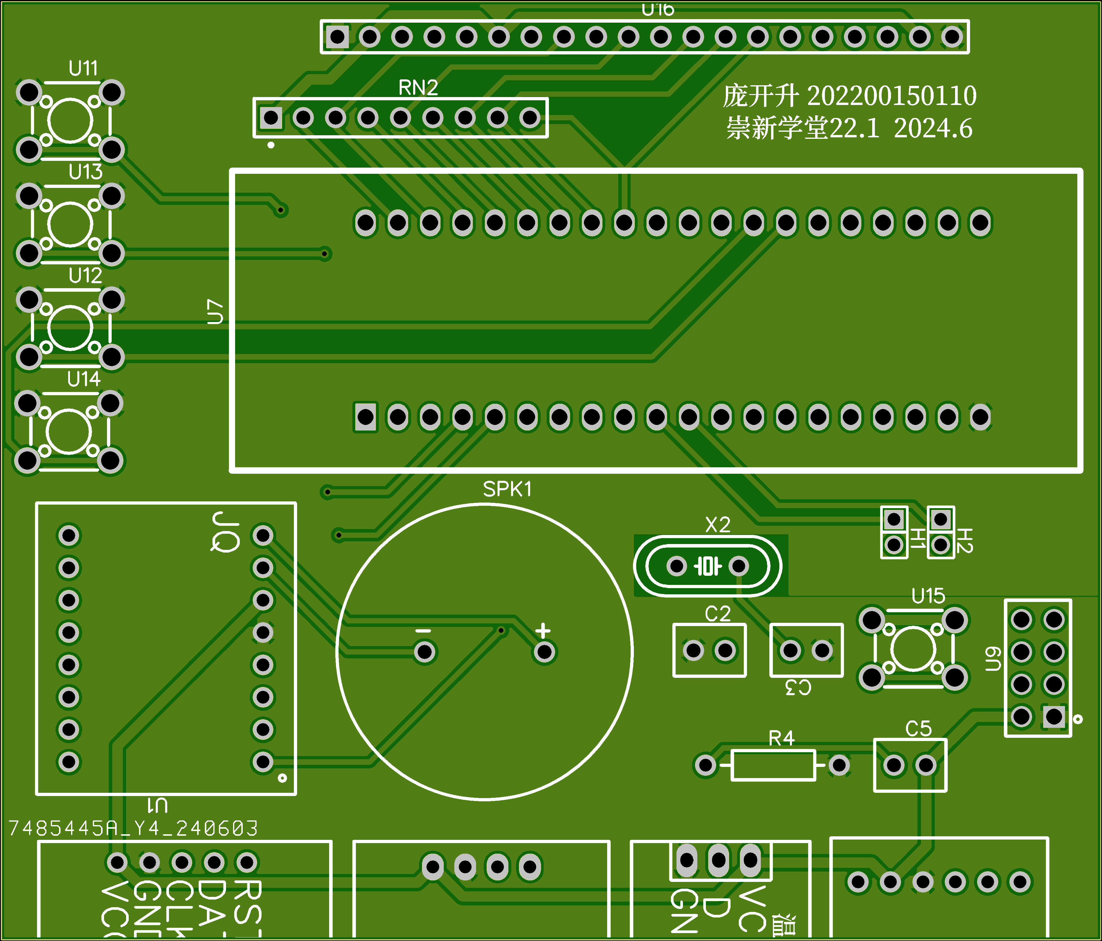
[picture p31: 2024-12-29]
PCB/实物仿真图.png

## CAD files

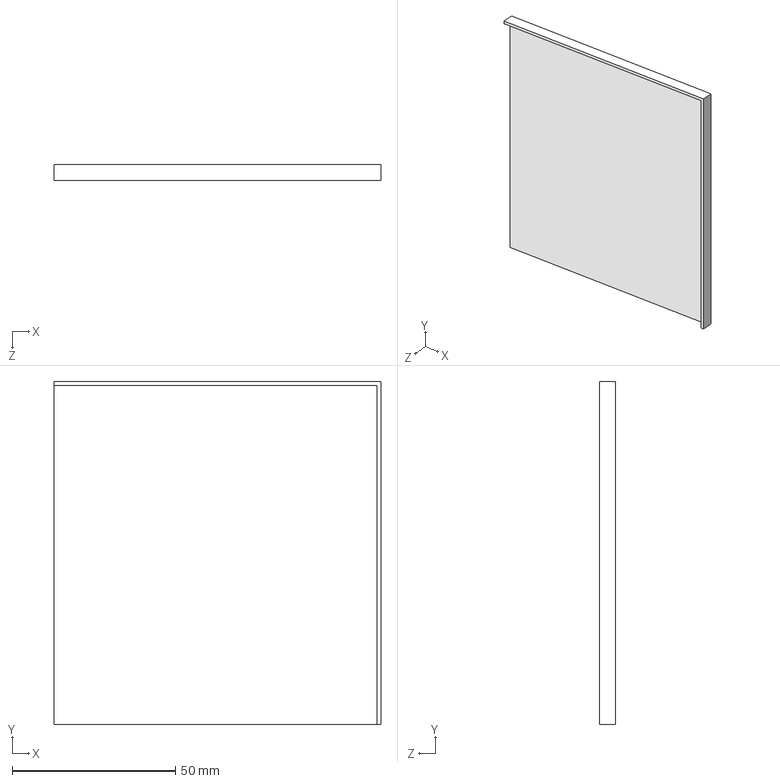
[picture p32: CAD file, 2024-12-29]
3D/盖子.STEP
100.0 x 105.0 x 5.00 mm

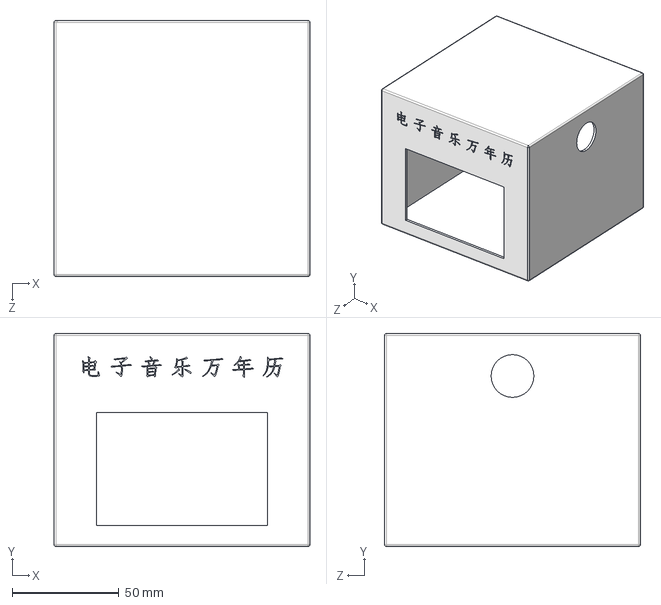
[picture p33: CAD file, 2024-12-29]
3D/盒子.STEP
120.0 x 100.0 x 120.0 mm

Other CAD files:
src/Objects/main.obj
src/Objects/dht11.obj
src/Objects/lunar.obj
src/Objects/STARTUP.obj
src/Objects/jq8900.obj
src/Objects/ds1302.obj
src/Objects/keyscan.obj
src/Objects/bluetooth.obj
src/Objects/12864.obj

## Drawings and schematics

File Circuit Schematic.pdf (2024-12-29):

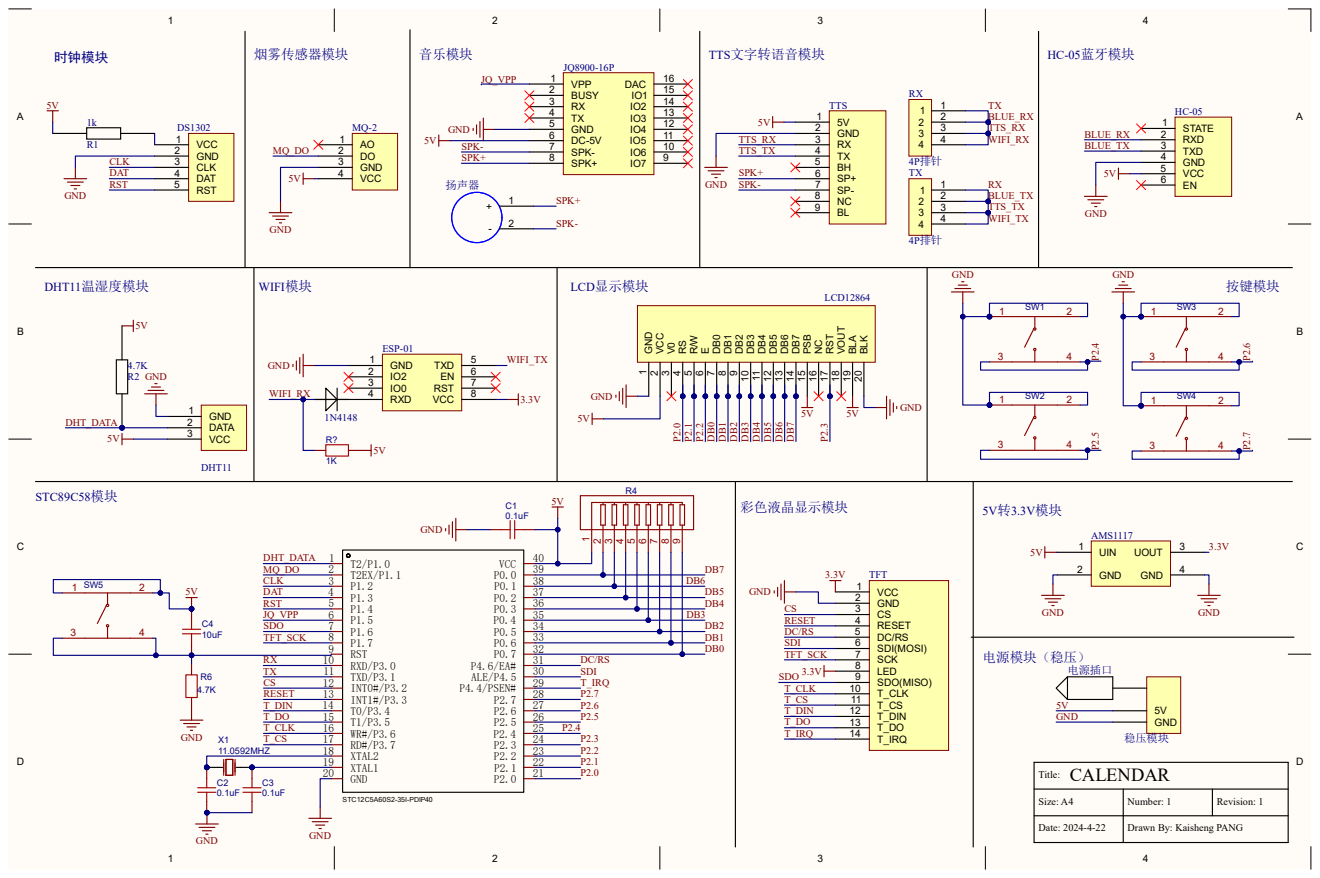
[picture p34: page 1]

9 DB3 10 DB4 11 DB5 12 DB6 13 DB7 14 PSB 15 NC 16 RST 17 VOUT 18 BLA 19 BLK 20

Size: A4 | Number: 1 | Revision: 1

Date: 2024-4-22 | Drawn By: Kaisheng PANG

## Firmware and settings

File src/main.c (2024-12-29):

# include <reg52.h>
# include "jq8900.h"
# include "lcd.h"
# include "ds1302.h"
# include "bluetooth.h"
sbit MQ2 = P1 ^ 1;

uchar key_scan();
void callMenu();
void Delay5Ms();
uchar* DHT11_receive();
void Delay30us();
void getweather();
void control();

//农历年相关驱动
void turn_lunar_calendar(uint year, uchar month, uchar day, uchar *lunar);
uchar judgeSolar(uint year,uchar month,uchar day);
uchar calculateWeekDay(uint year, uchar month, uchar day);

// 处理农历年的一些字符数组
uchar code TianGan[20] = "甲乙丙丁戊己  辛壬癸";
uchar code DiZhi[24] = "子丑寅卯辰巳午未申酉戌亥";
uchar code month_lunar[24] = "正二叁四五六七八九十冬腊";
uchar code first_day[6] = "初十廿";
uchar code second_day[20] = "一二叁四五六七八九十";
uchar code Solarterms[96] = "小寒大寒立春雨水惊蛰春分清明谷雨立夏小满芒种夏至小暑大暑立秋处暑白露秋分寒露霜降立冬小雪大雪冬至";
uchar code WeekDays[14] = "一二叁四五六日";

void main()
{
	// 初始化蓝牙
	Uart_Init_blue();
	// 初始化屏幕
	Lcm_Init();
	// 初始化时钟
	Ds1302Init();
	
	while(1)
		{
			// 变量声明
			uchar key;// 用来存储键值
			uchar clockvo[16] = "                ";// 用来暂存按下sw4出现的16位闹钟时间字符串
			
			// 获得displaydata1和2，用displaydata在第一行第二行显示
			dataProcess();
			Display_String(1, displayData);
			Display_String(2, displayData2);
			
			// dht11显示
			Display_String(3, DHT11_receive());
			
			// 占位
			
			Display_String(4,"KS CALENDAR 2024");
			
			// 按键检测
			key = key_scan();
			
			if (key == 1)
			{
				// 召唤菜单
				callMenu();
			}
			else if (key == 2)
			{
				SendData(0x0a);
				SendData(0x01);
				SendData(0x05);
				SendData(0x0c);
				SendData(0x0a);
				SendData(song);
				SendData(0x0b);
			}
			else if (key == 3)
			{
				SendData(0x0a);
				SendData(0x13);
				SendData(0x0b);
			}
			else if (key == 4)
			{
				
				Lcm_Init();
				while(1)
				{
					uchar key;
					clockvo[0] = clocktime[2] / 16 + '0';
					clockvo[1] = clocktime[2] % 16 + '0';
					clockvo[2] = ':';
					clockvo[3] = clocktime[1] / 16 + '0';
					clockvo[4] = clocktime[1] % 16 + '0';
					clockvo[5] = ':';
					clockvo[6] = clocktime[0] / 16 + '0';
					clockvo[7] = clocktime[0] % 16 + '0';
					Display_String(1, "闹钟时间:       ");
					Display_String(2, clockvo);
					Display_String(4, "按下 K4 返回主页");
					key = key_scan();
					if (key == 4)
					{
						break;
					}
				}
			}
						////闹钟时间检测
			
			if(alarmDetect())
			{
				SendData(0x0a);
				SendData(0x01);
				SendData(0x05);
				SendData(0x0c);//提高音量
				SendData(0x0a);
				SendData(song);
				SendData(0x0b);
				while(1)
					{
						Display_String(1, "    闹钟提醒    ");
						Display_String(2, "!!!!!!!!!!!!!!!!");
						Display_String(3, "!!!!!!!!!!!!!!!!");
						Display_String(4, "按下 K4 返回主页");
						key = key_scan();
						if(key == 4)
						{
							SendData(0x0a);
							SendData(0x13);
							SendData(0x0b);
							break;
						}
					}
			}
						if(MQ2 == 0)
			{
				Delay5Ms();
				if(MQ2 == 0)
				{
					SendData(0x0a);
					SendData(0x07);
					SendData(0x0b);
					PostChar(0x01);
					Lcm_Init();
					while(1)
					{
						Display_String(1, "  警报!!警报!!  ");
						Display_String(2, "  疑似火灾!!    ");
						Display_String(3, "  按下SW1 键继续");
						key = key_scan();
						if(key == 1)
						{
							SendData(0x0a);
							SendData(0x13);
							SendData(0x0b);
							break;
						}
					}
				}
			}
		}
}
void Basic(void)
{
	uchar key, i;
	uint year_t;
	uchar month_t, day_t;
	uchar TianGan_t, DiZhi_t;
	uchar lunar[2];
	uchar lunarinfo[16] = "                ";
	uchar month[2] = "月";
	uchar result;
	uchar weekday;
	uchar weekinfo[16] = "                ";
  uchar week[2] = "周";
	uchar threee[2] = "叁";
	uchar ten[2] = "十";
  Lcm_Init();
	
	while(1)
	{
		//dataprocess 用于读取TIME和生成displaydata
		dataProcess();
		year_t = 2000 + TIME[6] / 16 * 10 + TIME[6] % 16;
		month_t = TIME[4] / 16 * 10 + TIME[4] % 16;
		day_t = TIME[3] / 16 * 10 + TIME[3] % 16;
		
		TianGan_t = (year_t - 3) % 10;
		DiZhi_t = (year_t - 3) % 12;
		
		if(TianGan_t==0)TianGan_t=10;
		if(DiZhi_t==0)DiZhi_t=12;
		
		turn_lunar_calendar(year_t, month_t, day_t, lunar);
		result = judgeSolar(year_t, month_t, day_t);
		weekday = calculateWeekDay(year_t, month_t, day_t);
        for (i=0; i<2; i++) 
        {
            weekinfo[i] = week[i];
            weekinfo[i+2] = WeekDays[2*(weekday-1)+2+i];
        }

		for (i=0; i<2; i++)
		{
			lunarinfo[i] = TianGan[2 * (TianGan_t - 1) + i];//天干
			lunarinfo[i + 2] = DiZhi[2 * (DiZhi_t - 1) + i];//地支
			lunarinfo[i + 4] = month_lunar[2 * (lunar[0] - 1) + i-1];//月数
			lunarinfo[i + 6] = month[i];//“月”
			if(lunar[1] <= 10)
			{
				lunarinfo[i + 8] = first_day[i];//初十廿
				lunarinfo[i + 10] = second_day[2 * (lunar[1] - 1) + i];//1-10
			}
			else if(lunar[1] <= 19)
			{
				lunarinfo[i + 8] = first_day[i + 2];//初十廿
				lunarinfo[i + 10] = second_day[2 * (lunar[1] - 10 - 1) + i];//1-10
			}
			else if(lunar[1] <= 29)
			{
				lunarinfo[i + 8] = first_day[i + 4];//初十廿
				lunarinfo[i + 10] = second_day[2 * (lunar[1] - 20 - 1) + i];//1-10
			}		
			else if(lunar[1] == 30)
			{
				lunarinfo[i + 8] = threee[i];//叁十
				lunarinfo[i + 10] = ten[i];
			}			
		}
		if(result)
		{
			lunarinfo[12] = Solarterms[4 * result];
			lunarinfo[13] = Solarterms[4 * result + 1];
			lunarinfo[14] = Solarterms[4 * result + 2];
			lunarinfo[15] = Solarterms[4 * result + 3];
		}
		else
		{
			lunarinfo[12] = ' ';
			lunarinfo[13] = ' ';
			lunarinfo[14] = ' ';
			lunarinfo[15] = ' ';
		}
		
		Display_String(1, displayData);
		Display_String(2, displayData2);
		Display_String(3, lunarinfo);
		Display_String(4, weekinfo);
		
		key = key_scan();
		if(key == 4)
		{
			return;
		}
	}
	
}

uchar calculateWeekDay(uint year, uchar month, uchar day)
{
    uint century;
    uint yearInCentury;
    uchar weekday;
    

    if (month == 1 || month == 2)
    {
        month += 12;
        year--;
    }
    
    century = year / 100;
    yearInCentury = year % 100;
    

    weekday = (day + 2 * month + 3 * (month + 1) / 5 + yearInCentury + yearInCentury / 4 + century / 4 - 2 * century) % 7;
    

    if (weekday < 0) 
    {
        weekday += 7;
    }
    
    return weekday;
}



void callMenu()
{
	uchar flag = 1;
	uchar test = 0x01;
	uchar key0;
	Lcm_Init();
	while(1)
	{
		Delay30us();
		key0 = key_scan();
		if (key0 == 1)
		{
			if (flag == 1)
			{
			}
			else if (flag == 2)
			{
				Basic();
			}
			else if (flag == 3)
			{
				dataChange();
			}
			else if (flag == 4)
			{
				setClock();
			}
			else if (flag == 5)
			{
				Musicselect();
			}
			else if (flag == 6)
			{
				getweather();
			}
			else if (flag == 7)
			{
				control();
			}
			else if (flag == 8)
			{
				return;
			}
			else
			{
			}
		}
		else if (key0 == 2)
		{
			flag++;
			if (flag == 9)flag = 1;
		}
		else if (key0 == 3)
		{
			break;
		}
		if (flag == 1)
		{
			Display_String(1, "K2选中    K1进入");
			Display_String(2, "1.基础显示      ");
			Display_String(3, "2.修改时间      ");
			Display_String(4, "3.设置闹钟      ");
		}
		else if (flag == 2)
		{
			Display_String(1, "K2选中    K1进入");
			Display_String(2, "1.基础显示    选");
			Display_String(3, "2.修改时间      ");
			Display_String(4, "3.设置闹钟      ");
		}
		else if (flag == 3)
		{
			Display_String(1, "K2选中    K1进入");
			Display_String(2, "1.基础显示      ");
			Display_String(3, "2.修改时间    选");
			Display_String(4, "3.设置闹钟      ");
		}
		else if (flag == 4)
		{
			Display_String(1, "K2选中    K1进入");
			Display_String(2, "1.基础显示      ");
			Display_String(3, "2.修改时间      ");
			Display_String(4, "3.设置闹钟    选");
		}
		else if (flag == 5)
		{
			Display_String(1, "1.基础显示      ");
			Display_String(2, "2.修改时间      ");
			Display_String(3, "3.设置闹钟      ");
			Display_String(4, "4.设置铃声    选");
		}
		else if (flag == 6)
		{
			Display_String(1, "2.修改时间      ");
			Display_String(2, "3.设置闹钟      ");
			Display_String(3, "4.设置铃声      ");
			Display_String(4, "5.获取天气    选");
		}
		else if (flag == 7)
		{
			Display_String(1, "3.设置闹钟      ");
			Display_String(2, "4.设置铃声      ");
			Display_String(3, "5.获取天气      ");
			Display_String(4, "6.事项提醒    选");
		}
		else if (flag == 8)
		{
			Display_String(1, "4.设置铃声      ");
			Display_String(2, "5.获取天气      ");
			Display_String(3, "6.事项提醒      ");
			Display_String(4, "7.返回        选");
		}
	}
}

void getweather()
{
	uchar key;
	Lcm_Init();
	while(1)
	{
		Display_String(1, "请连接手机App   ");
		if(weather == 25)
		{
			Display_String(3, "晴朗天气        ");
		}
		else if(weather == 26)
		{
			Display_String(3, "多云天气        ");
		}
		else if(weather == 27)
		{
			Display_String(3, "少云天气        ");
		}
		else if(weather == 28)
		{
			Display_String(3, "晴间多云        ");
		}
		else if(weather == 29)
		{
			Display_String(3, "阴天  南风      ");
		}
		else if(weather == 30)
		{
			Display_String(3, "阵雨            ");
		}
		else if(weather == 31)
		{
			Display_String(3, "强阵雨          ");
		}
		else if(weather == 32)
		{
			Display_String(3, "雷阵雨          ");
		}
		else if(weather == 33)
		{
			Display_String(3, "强雷阵雨        ");
		}
		else if(weather == 34)
		{
			Display_String(3, "小雨            ");
		}
		else if(weather == 35)
		{
			Display_String(3, "中雨            ");
		}
		else if(weather == 36)
		{
			Display_String(3, "大雨            ");
		}
		else if(weather == 37)
		{
			Display_String(3, "暴雨            ");
		}
		else if(weather == 38)
		{
			Display_String(3, "大暴雨          ");
		}
		else if(weather == 39)
		{
			Display_String(3, "  雨            ");
		}
		else if(weather == 50)
		{
			Display_String(3, "  生            ");
		}
		else
		{
		}
		key = key_scan();
		if(key == 4)
		{
			return;
		}
	}
}

void control()
{
	uchar key;
	Lcm_Init();
	while(1)
	{
		Display_String(1, "    事项提醒    ");
		if(weather == 50)
		{
		Display_String(3, "    生日提醒    ");
		}
		else if(weather == 51)
		{
		Display_String(3, "    会议提醒    ");
		}
		else if(weather == 52)
		{
		Display_String(3, "  作业截止提醒  ");
		}
		else if(weather == 53)
		{
		Display_String(3, "    实验提醒    ");
		}
		key = key_scan();
		if(key == 4)
		{
			return;
		}
	}
}
